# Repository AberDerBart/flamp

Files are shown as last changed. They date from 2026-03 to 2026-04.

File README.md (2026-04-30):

**Disclaimer:** This has been developed as a personal project and the current state was good enough for me to build it but is problably not well suited to recreate.
There are also changes planned (especially to the PCB and electronics).
Please contact me or open an issue if you have any problems or questions on this project, I am happy to help (but not very motivated to do documentation work upfront).

If you want or need another license for some reason (especially for commercial use), feel free to contact me.

# Flamp

These are the design files for my flower lamp (short "Flamp"), A dimmable ceiling lamp inspired by a flower blossom with servo-actuated petals to open up or close down.

## Getting started

Check out this repository using the [`--recurse-submodules`](https://git-scm.com/docs/git-clone#Documentation/git-clone.txt---recurse-submodulespathspec) flag.

For the mechanical design, open `lamp.scad` in OpenSCAD. This gives an overview how the lamp is assembled.

For the PCB design, open [pcb/pcb.kicad_pro](pcb/pcb.kicad_pro) in KiCad.

## Necessary parts

For hardware and electronic parts, see [BOM.csv](BOM.csv).
You need to 3D print the parts from [cad/printed_parts.scad](cad/printed_parts.scad).
The design for the wooden parts can be found in [cad/wooden_parts_12mm.scad](cad/wooden_parts_12mm.scad) and [cad/wooden_parts_4mm.scad](cad/wooden_parts_4mm.scad).

1. Cut the parts with a CNC router or laser cutter from 12mm or 4mm plywood respectively
2. 3D print the [jigs](cad/jigs.scad) and use them to trace the shape of the wooden parts and saw them out.
   Then, use the jigs and a router to trim them to size and drill the holes using the jigs. Make sure to drill the holes before removing the inner parts.

## Assembly

TODO

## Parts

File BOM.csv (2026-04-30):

Part | Amount
683 ZZ Bearing | 6
MF83 ZZ Bearing | 10
F635 ZZ Bearing | 3
Wood screws 1.4 x 4mm | 66
Screws M3 x 6mm ISO 7380 | 23
Screws M3 x 8mm ISO 7380 | 57
Screws M3 x 25mm ISO 7380 | 5
Screws M5 x 20mm (?) | 3
Screws M3 x 35mm | 10
Screws M4 x 35mm cone | 10
Screws M4 x 10mm | 4
M4 screw-in nuts | 10
Zip Tie 3mm | 2
Wood screws 3.5 x 17mm | 13
Acrylic glass mirror, round, diameter 30cm, thickness 3mm | 1
Acrylic glass diffusor, round, diameter 30cm, thickness 3mm | 1
Power supply
LED strip warm white/cold white | ~2m
PCB | 1
Raspberry Pi Pico WH | 1
Standard size servo (40x20mm) | 1
IRLZ34N MOSFET | 4
Resistor 10kOhm 1206 | 4
Resistor 100Ohm 1206 | 4
Pin header 3x1 2.54mm | 1
Socket header 20x1 2.54mm | 2
Screw Terminal 3x1 5mm | 2
Screw Terminal 2x1 5mm | 1
Cables for LED strip (might be included with LED strip) | ~30cm

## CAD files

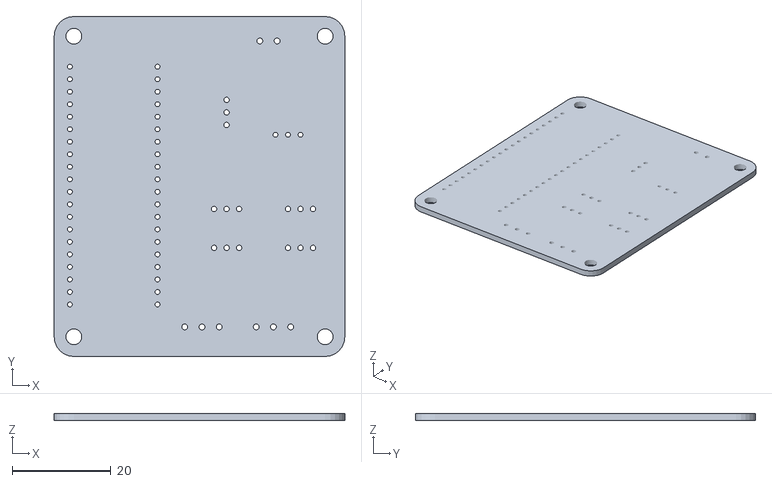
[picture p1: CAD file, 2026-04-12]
cad/pcb.stl
59.0 x 69.0 x 1.51

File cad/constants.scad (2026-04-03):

use <bartscad/tr.scad>

H_BASE=12;
H_LEAVES=3.7;
H_CONTROL_RING=4;
H_LEAF_GAP=12;
H_LINKS=3;

LINK_CONTROL_ANGLES=[0,24];
L_BOTTOM_LEAF_LINKS=[70,45];

H_SUPPORT_RING=12;
H_TOP_SUPPORT_RING=16;

Z_LEAVES_1 = H_BASE;
Z_SUPPORT_1 = Z_LEAVES_1 + H_LEAF_GAP;
Z_LEAVES_2 = Z_SUPPORT_1 + H_SUPPORT_RING;
Z_SUPPORT_2 = Z_LEAVES_2 + H_LEAF_GAP;
Z_LEAVES_TOP = Z_SUPPORT_2 + H_TOP_SUPPORT_RING;

Z_CONTROL_RING=Z_SUPPORT_1 + H_SUPPORT_RING/2 - H_CONTROL_RING/2;
Z_CONTROL_RING_BEARING_STACK=Z_CONTROL_RING-8-3-6+1.5+H_CONTROL_RING+H_CONTROL_RING;

CHAMFER_TOP_SUPPORT_RING = 10/sqrt(2);

R_CONTROL_RING_INNER=85;
R_CONTROL_RING_BEARING=9.5;
R_CONTROL_RING_BEARING_MOUNT=R_CONTROL_RING_INNER-R_CONTROL_RING_BEARING;
ANGLE_CONTROL_RING_BEARING=38;

R_STRUCTURE=180;

D_TOP_LEAF_MOUNTING_SCREW=1.5;

OFFSET_TILT_ROLLER=145;
ANGLE_OFFSET_TILT_ROLLER=asin(OFFSET_TILT_ROLLER/(2*R_STRUCTURE));

Z_LIGHT_FIXTURE=Z_SUPPORT_2+12;
R_LIGHT_FIXTURE=150;
R_DIFFUSOR_DOME=450;
ANGLE_LIGHT_FIXTURE=-30;

ANGLE_CONTROL_RING_MAX=115;
ANGLE_CONTROL_RING_MIN=90;

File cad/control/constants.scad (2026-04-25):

ANGLE_CENTER=180;

BEARING_INDEXES=[1,2,4];

TR_POWER_SUPPLY=rz(ANGLE_CENTER)*t(0,-30,Z_CONTROL_RING_BEARING_STACK);
TR_PCB=rz(ANGLE_CENTER)*t(10,29,Z_CONTROL_RING_BEARING_STACK+15)*rz(-90);

MM_PER_TOOTH=2.6;
TEETH_SERVO=25;
TEETH_CONTROL_RING=180;

ANGLE_CONTROL_RING_TRAVEL=ANGLE_CONTROL_RING_MAX-ANGLE_CONTROL_RING_MIN;

R_SERVO=72;
Z_SERVO=23.5;

TR_SERVO=rz(ANGLE_CENTER)*t(y=R_SERVO,z=Z_SERVO) * rx(-90);

POS_CABLE_GUIDE=[0,67];
R_SERVO_LINK=72;
SERVO_TRAVEL=R_SERVO_LINK*sin(ANGLE_CONTROL_RING_TRAVEL/2)*2;

OFFSET_Z_CONTROL_RAIL=8;

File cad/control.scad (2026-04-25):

use <bartscad/bearings.scad>
use <bartscad/servos.scad>
use <bartscad/linkage.scad>
use <bartscad/poly.scad>
use <bartscad/origins.scad>

use <BOSL/involute_gears.scad>

include <constants.scad>

use <link.scad>
use <util.scad>
include <electronics.scad>

include <control/constants.scad>
use <control/frame.scad>
use <control/cable_guide.scad>
use <control/drive_cam.scad>
use <control/bearing_washer.scad>
include <control/ring.scad>

function tr_servo_gear_peg(a_servo) = tz(Z_SERVO) * rz(ANGLE_CENTER+90) * rx(a_servo) * rz(ANGLE_CONTROL_RING_TRAVEL/2)*ry(90)*tz(R_SERVO_LINK);

function a_control_ring(a_servo) = asin(cos(a_servo)*SERVO_TRAVEL/2/R_SERVO_LINK);

module servo(){
  #tr(TR_SERVO)translate([0,0,-10])servo_joy_it();
  drive_cam();
}

module control_ring_bearing_stack() {
  translate([0,0,8]){
    control_bearing_washer();
    translate([0,0,9])scale([1,1,-1])bearing_f635();
  }
}

module control_frame_assembly(){
  control_frame();
  translate([0,0,Z_CONTROL_RING_BEARING_STACK]){
    rotate([0,0,ANGLE_CONTROL_RING_BEARING])for(i=BEARING_INDEXES){
      rotate([0,0,360/5*i])translate([R_CONTROL_RING_BEARING_MOUNT,0])control_ring_bearing_stack();
    }
  }
  tr(TR_POWER_SUPPLY)power_supply();
  *tr(TR_PCB)pcb();
  cable_guide();
}

module control_drill_jig(){
  linear_extrude(3) difference(){
    union(){
      hull(){
        circle(d=10);
        rotate([0,0,72+22.5])translate([105,0])circle(d=10);
      }
      hull(){
        rotate([0,0,72+22.5])translate([105,0])circle(d=10);
        rotate([0,0,72+12])translate([R_STRUCTURE,0])circle(d=10);
      }
    }
    circle(d=5);
    rotate([0,0,72+22.5])translate([105,0])circle(d=2);
    rotate([0,0,72+12])translate([R_STRUCTURE,0])circle(d=4);
  }
}

control_frame_assembly();
servo();
tr(tz(Z_CONTROL_RING)*rz(90))control_ring();
$fn=360;

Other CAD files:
cad/control/bearing_washer.scad
cad/bottom_leaves.scad
cad/bottom_leaves/bracket.scad
cad/bottom_leaves/leaf.scad
cad/bottom_leaves/link.scad
cad/control/cable_guide.scad
cad/control/drive_cam.scad
cad/control/frame.scad
cad/control/ring.scad
cad/control/ring_bracket.scad
cad/control/ring_core.scad
cad/control/ring_rail.scad
cad/electronics.scad
cad/jigs.scad
cad/lamp.scad
cad/leaf.scad
cad/light-fixture.scad
cad/light_fixture/diffusor_clamp.scad
cad/light_fixture/rim.scad
cad/link.scad
cad/mounting_tab.scad
cad/printed_parts.scad
cad/structure.scad
cad/structure/support.scad
cad/top_leaves.scad
cad/top_leaves/bracket.scad
cad/top_leaves/hinge.scad
cad/top_leaves/leaf.scad
cad/top_leaves/link.scad
cad/top_leaves/tilt_rail.scad
cad/top_leaves/tilt_roller.scad
cad/top_leaves/util.scad
cad/util.scad
cad/wooden_parts_12mm.scad
cad/wooden_parts_4mm.scad

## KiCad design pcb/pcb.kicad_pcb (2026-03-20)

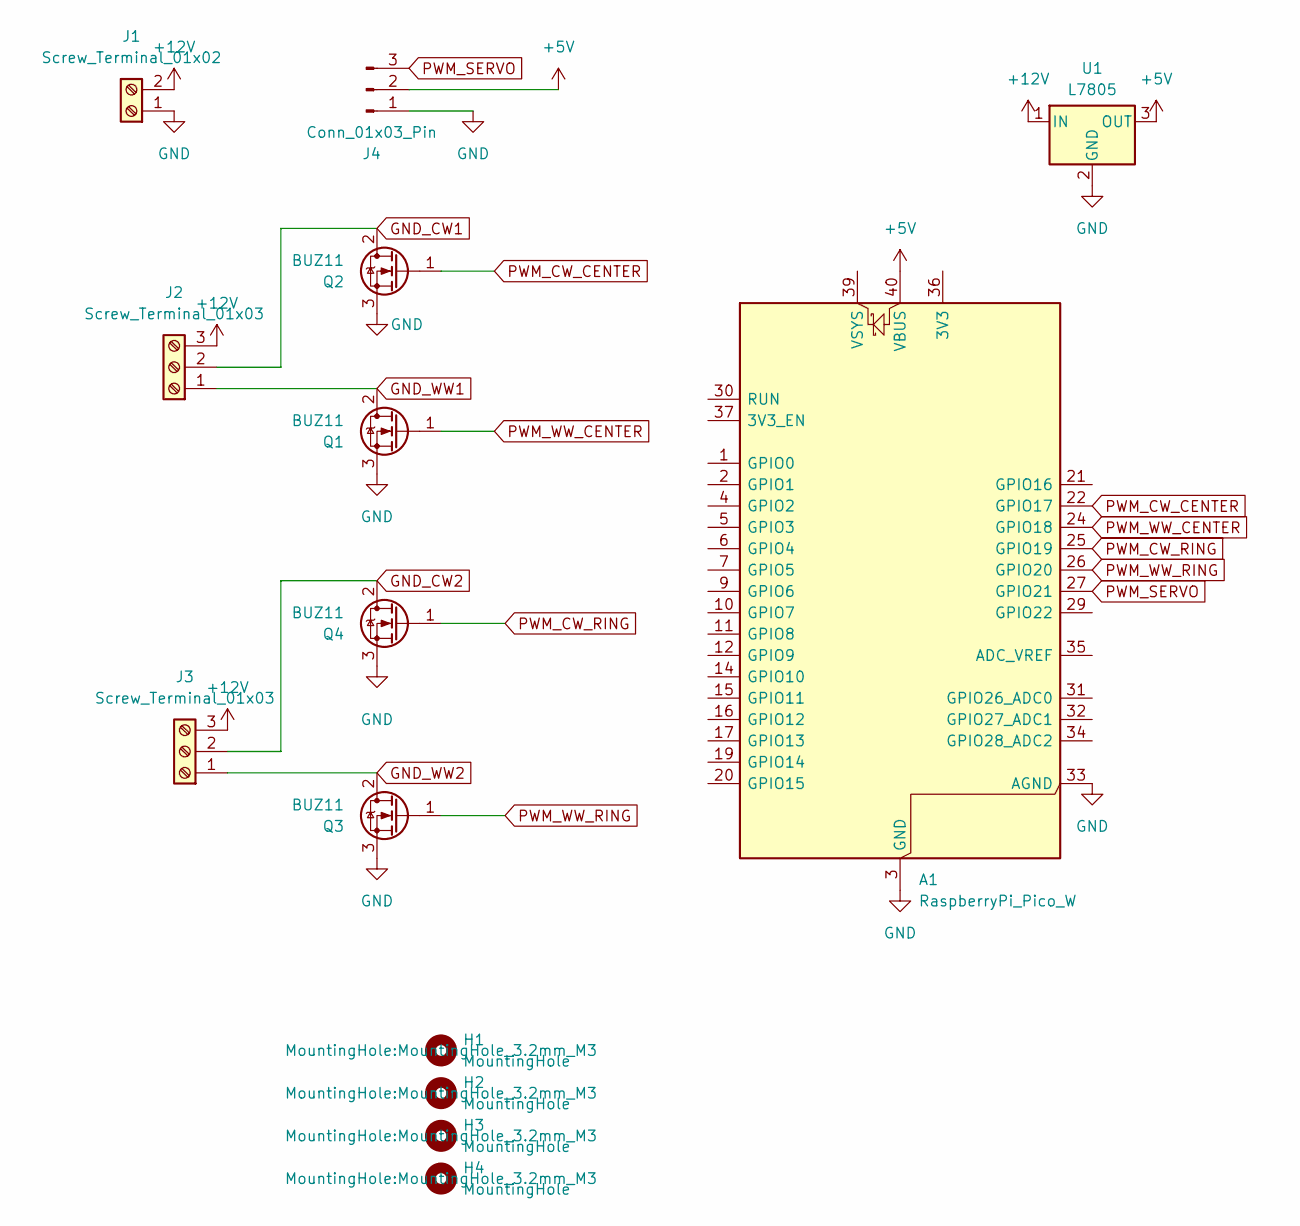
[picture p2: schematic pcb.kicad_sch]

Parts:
A1: RaspberryPi_Pico_W; RaspberryPi_Pico_Common_THT
H1, H2, H3, H4: MountingHole; MountingHole_3.2mm_M3
J1: Screw_Terminal_01x02; TerminalBlock_Phoenix_PT-1,5-2-3.5-H_1x02_P3.50mm_Horizontal
J2, J3: Screw_Terminal_01x03; TerminalBlock_Phoenix_PT-1,5-3-3.5-H_1x03_P3.50mm_Horizontal
J4: Conn_01x03_Pin; PinHeader_1x03_P2.54mm_Vertical
Q1, Q2, Q3, Q4: BUZ11; TO-220-3_Horizontal_TabDown
U1: L7805; TO-220-3_Horizontal_TabUp

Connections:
+5V: A1.40 (VBUS), J4.2, U1.3 (OUT)
+12V: J1.2, J2.3, J3.3, U1.1 (IN)
GND: A1.3 (GND), A1.8 (GND), A1.13 (GND), A1.18 (GND), A1.23 (GND), A1.28 (GND), A1.33 (AGND), A1.38 (GND), J1.1, J4.1, Q1.3 (S), Q2.3 (S), Q3.3 (S), Q4.3 (S), U1.2 (GND)
GND_CW1: J2.2, Q2.2 (D)
GND_CW2: J3.2, Q4.2 (D)
GND_WW1: J2.1, Q1.2 (D)
GND_WW2: J3.1, Q3.2 (D)
PWM_CW_CENTER: A1.22 (GPIO17), Q2.1 (G)
PWM_CW_RING: A1.25 (GPIO19), Q4.1 (G)
PWM_SERVO: A1.27 (GPIO21), J4.3
PWM_WW_CENTER: A1.24 (GPIO18), Q1.1 (G)
PWM_WW_RING: A1.26 (GPIO20), Q3.1 (G)

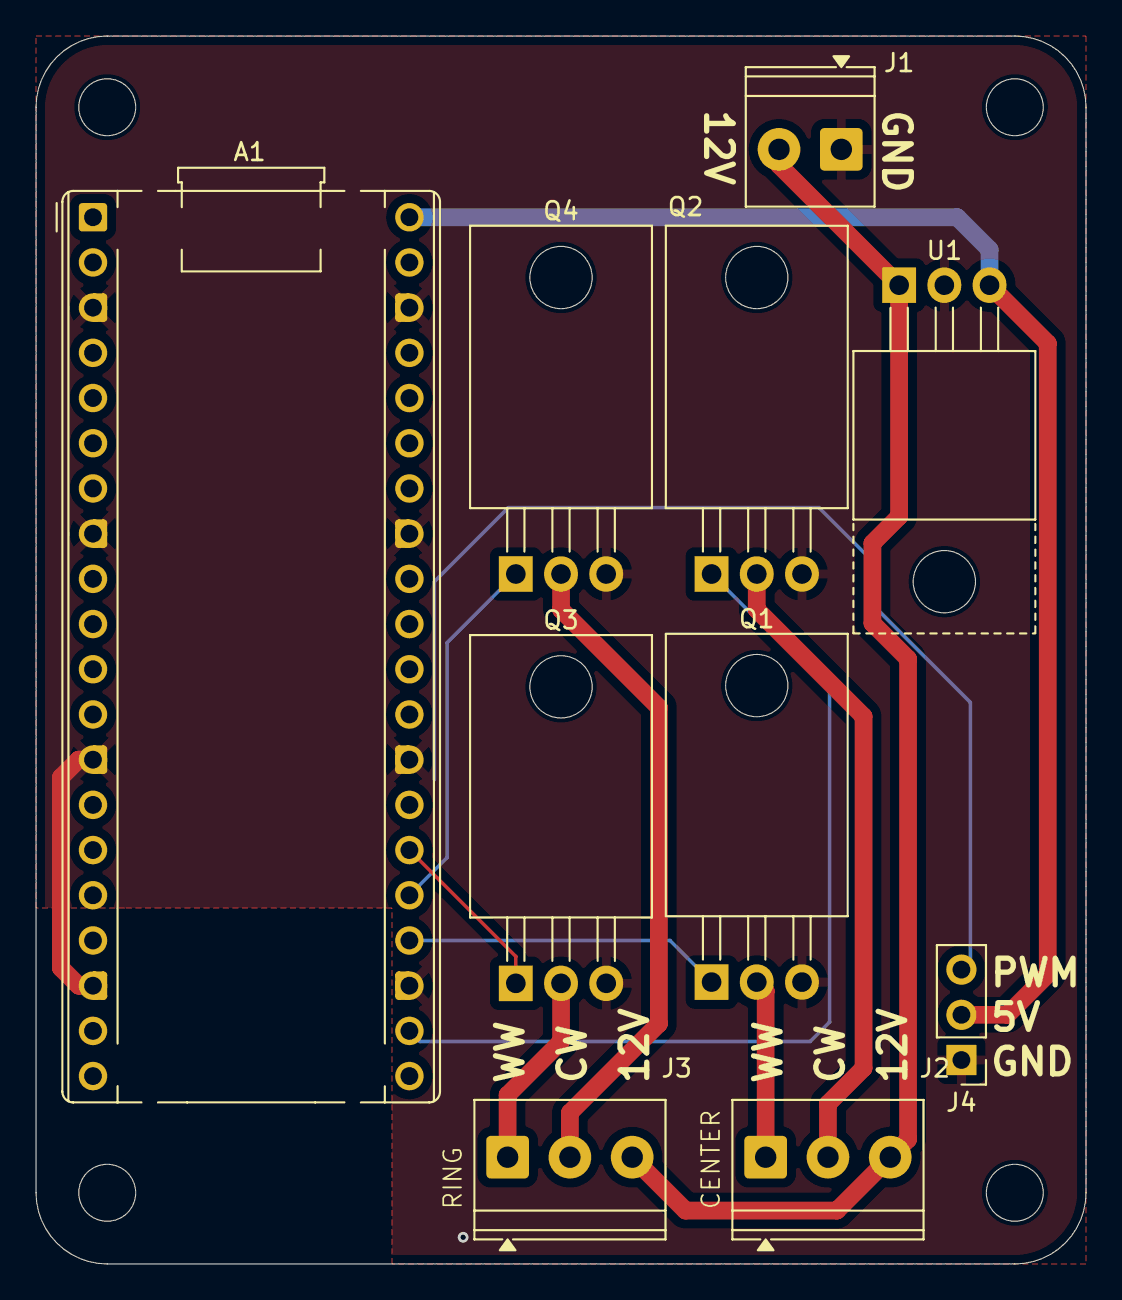
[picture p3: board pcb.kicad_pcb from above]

Board: 2 copper layers, 59.0 x 69.0 mm, 14 parts (0 on the bottom side), 12 nets.

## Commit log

2026-01-09 add bottom leaf links
    [lamp.scad]
2026-01-12 add linkages
    [lamp.scad]
2026-01-17 add servo and bearings
    [lamp.scad]
2026-01-19 restructure code
    [lamp.scad]
2026-01-20 model top support ring
    [lamp.scad]
2026-01-21 curve links
    [lamp.scad]
2026-01-21 fine-tune mechanism
    [lamp.scad]
2026-01-31 redesign top leaf arms
    [lamp.scad]
2026-01-31 split up files
    [constants.scad, lamp.scad, leaf.scad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]
2026-02-01 move more stuff to separate files
    [bottom_leaves.scad, constants.scad, lamp.scad]
2026-02-06 more refinements
    [bottom_leaves.scad, constants.scad, lamp.scad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]
2026-02-11 animate top leaf tilt
    [top_leaves.scad, util.scad]
2026-02-12 add top leaf tilt rail
    [top_leaves.scad]
2026-02-15 add tilt support roller
    [constants.scad, structure.scad, top_leaves.scad]
2026-02-16 adjust top leaf angles
    [mounting_tab.scad, top_leaves.scad]
2026-02-19 improve top leaf hinge and rai
    [constants.scad, structure.scad, top_leaves.scad]
2026-02-21 add top leaf hinge roller mounting hole
    [structure.scad]
2026-02-21 improve top leaves 3d printed parts
    [top_leaves.scad]
2026-02-21 adjust top leaf linkag
    [constants.scad, lamp.scad, top_leaves.scad]
2026-03-11 add control structure
    [constants.scad, control.scad, lamp.scad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]
2026-03-11 add pcb
    [pcb.kicad_pcb, pcb.kicad_sch]
2026-03-12 improve bottom leaf spacer
    [bottom_leaves.scad]
2026-03-13 add stopper to bottom leaf link
    [bottom_leaves.scad, control.scad]
2026-03-14 fixup! add control structure
    [lamp.scad]
2026-03-17 make top leaf hinges detachable
    [top_leaves.scad]
2026-03-17 model light fixture attachment points and extract electronics
    [constants.scad, electronics.scad, light-fixture.scad]
2026-03-17 redesign top leaf roller
    [top_leaves.scad]
2026-03-17 mount electronics to control_frame
    [bottom_leaves.scad, control.scad, electronics.scad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]
2026-03-17 Revert "make top leaf hinges detachable"
    This reverts commit d38aec6823b7c8e77f104803ede591a39ca52cfc.
    [top_leaves.scad]
2026-03-20 close off top leaf tilt rail
    [top_leaves.scad]
2026-03-20 add snap-fit connector to top leaf hinge
    [top_leaves.scad]
2026-03-20 fix pcb issues
    [pcb.kicad_pcb, pcb.kicad_sch]
2026-03-20 fixup! add snap-fit connector to top leaf hinge
    [constants.scad]
2026-03-22 make space for electronics
    [constants.scad, light-fixture.scad]
2026-03-22 add drill holes for light fixture
    [structure.scad]
2026-03-23 improve top leaf assembly jig
    [top_leaves.scad]
2026-03-23 add glue jig
    [structure.scad]
2026-03-25 finalize light fixture
    [light-fixture.scad]
2026-03-27 redesign control frame
    [control.scad]
2026-03-27 add light fixture diffusor clamps
    [light-fixture.scad]
2026-03-30 fixup! redesign control frame
    [control.scad]
2026-03-30 make top frame hinges slidable with snap-fit
    [top_leaves.scad]
2026-04-03 finalize design (for now...)
    [constants.scad, control.scad, lamp.scad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]
2026-04-12 add pcb stl model
    [pcb.stl]
2026-04-25 move cad files to subfolder
    [bottom_leaves.scad, constants.scad, control.scad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]
2026-04-25 extract parts into separate files
    [bottom_leaves.scad, bracket.scad, control.scad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]
2026-04-25 replace excenters with printed material
    [control.scad]
2026-04-25 move remaining printed parts into their own files
    [bearing_washer.scad, cable_guide.scad, constants.scad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]
2026-04-25 split up structure parts by used wood
    [leaf.scad, structure.scad, wooden_parts_12mm.scad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]
2026-04-25 add jigs file
    [jigs.scad, leaf.scad, top_leaves.scad]
2026-04-30 add BOM and update README
    [BOM.csv]
